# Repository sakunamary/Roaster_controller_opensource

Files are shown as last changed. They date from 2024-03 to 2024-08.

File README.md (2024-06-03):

# 全热风咖啡烘豆机主控板，适合自己diy用。

## 性能特点
- 2路温度采集：bt和inlet
- 温度采集使用max6675 k型热电偶
- 无线连接artisan
- 0-10v连续模拟输出，可以控制工业用可控硅
- 风机使用12/24v无刷控制。
- 留有I2C接口可以接扩展传感器、oled等。
  
## 目前开源板程序功能如下：
- 1：为无线接artisan记录温度数据
- 2：手动控制风力和火力。

## 相关资源
- 硬件推荐：

        1.风扇控制:模型电调(3s-4s,40A 以上的就OK)，pwm频率为50Hz，分辨率可以选择参数10（0-1024档）或者9（512档）。
        2.可控硅: MGR 2440 (0-10V，40A输出)

- 硬件开源地址：https://oshwhub.com/sakunamary/re-feng-ji-kong-zhi-ban-kai-yuan
- 固件开源地址：
  
        1.https://github.com/sakunamary/Roaster_controller_opensource

        2.https://gitee.com/sakunamary/Roaster_controller_opensource

- 操作视频：
  
        1.https://www.bilibili.com/video/BV1eg411e7H4/（怎么链接模块的Wi-Fi）
  
        2.https://www.bilibili.com/video/BV1et4y1w7i5/ （artisan怎么链接）

        3.https://www.bilibili.com/video/BV1AV4y1L7yL/ （artisan的基本操作）

## 特别提醒
本项目是开源项目，欢迎集成新功能进来、修改bug。请注意本项目的软件和硬件使用的是非商业版权授权协议的。如果需要做商业用途，请自行做闭源软硬件设计。控制原理就是那点东西了，请不要做拿来党。

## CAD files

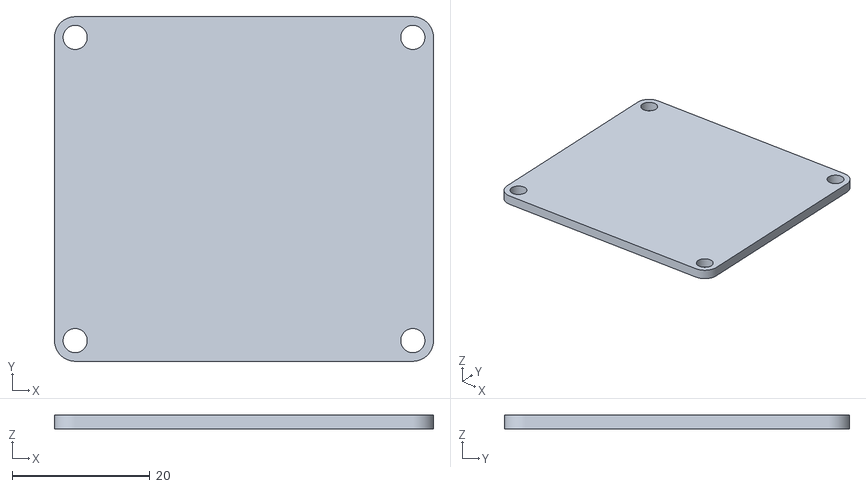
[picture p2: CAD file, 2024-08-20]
reference/保护板.stl
55.0 x 50.0 x 2.00

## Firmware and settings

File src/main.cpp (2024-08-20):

#include <Arduino.h>
#include <config.h>
#include <WiFi.h>
#include <TASK_read_temp.h>
#include <TASK_modbus_control.h>

String local_IP;

char ap_name[30];
uint8_t macAddr[6];

// HardwareSerial Serial(0);

void Task_modbus_control(void *pvParameters);
void Task_Thermo_get_data(void *pvParameters);

void setup()
{

    xThermoDataMutex = xSemaphoreCreateMutex();

    Serial.begin(BAUDRATE);

#if defined(DEBUG_MODE)
    Serial.printf("\nHOT AIR ROASTER STARTING...\n"); // 启动setup
#endif

    pwm.pause();
    pwm.write(pwm_fan_out, 0, frequency, resolution);
    pwm.write(pwm_heat_out, 0, frequency, resolution);
    pwm.resume();

#if defined(DEBUG_MODE)
    Serial.printf("\nStart PWM...\n"); // 初始化 pwm
    pwm.printDebug();
#endif

    // 初始化网络服务
    WiFi.macAddress(macAddr);
    WiFi.mode(WIFI_AP);
    sprintf(ap_name, "ROASTER_%02X%02X%02X", macAddr[3], macAddr[4], macAddr[5]);
    WiFi.softAP(ap_name, "roaster8888"); // defualt IP address :192.168.4.1 password min 8 digis

#if defined(DEBUG_MODE)
    Serial.printf("\nAP NAME:%s...\n", ap_name);
#endif

#if defined(DEBUG_MODE)
    Serial.printf("Start Task...\n");
#endif

    /*---------- Task Definition ---------------------*/
    // Setup tasks to run independently.
    xTaskCreate(
        Task_Thermo_get_data, "Thermo_get_data" // 获取温度数据的任务
        ,
        1024 * 6 // This stack size can be checked & adjusted by reading the Stack Highwater
        ,
        NULL, 1 // Priority, with 1 (configMAX_PRIORITIES - 1) being the highest, and 0 being the lowest.
        ,
        NULL // Running Core decided by FreeRTOS,let core0 run wifi and BT
    );
#if defined(DEBUG_MODE)
    Serial.printf("TASK1:Task_Thermo_get_data...\n");
#endif

    xTaskCreate(
        Task_modbus_control, "modbus_control" // 获取监控artisan操控的任务
        ,
        1024 * 10 // This stack size can be checked & adjusted by reading the Stack Highwater
        ,
        NULL, 2 // Priority, with 1 (configMAX_PRIORITIES - 1) being the highest, and 0 being the lowest.
        ,
        NULL // Running Core decided by FreeRTOS,let core0 run wifi and BT
    );
#if defined(DEBUG_MODE)
    Serial.printf("TASK2:Task_modbus_control...\n");
#endif

#if defined(DEBUG_MODE)
    Serial.printf("Start Modbus-TCP   service...\n");// 初始化Modbus-TCP服务

#endif
    mb.server(502); // Start Modbus IP //default port :502
    mb.addHreg(BT_HREG);
    mb.addHreg(ET_HREG);
    mb.addHreg(HEAT_HREG);
    mb.addHreg(FAN_HREG);

    mb.Hreg(BT_HREG, 0);   // 初始化赋值
    mb.Hreg(ET_HREG, 0);   // 初始化赋值
    mb.Hreg(HEAT_HREG, 0); // 初始化赋值
    mb.Hreg(FAN_HREG, 0);  // 初始化赋值
}

void loop()
{
    mb.task();
}

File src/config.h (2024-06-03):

#ifndef __CONFIG_H__
#define __CONFIG_H__

#include <Wire.h>

#define uS_TO_S_FACTOR 1000000 /* Conversion factor for micro seconds to seconds */
#define BAUDRATE 115200        // serial port baudrate

// #define DEBUG_MODE  //是否输出debug信息

#define VERSION "1.0.3"

#define SPI_SCK 8
#define SPI_MISO 9
#define SPI_MOSI 10

#define SPI_CS_BT 4
#define SPI_CS_ET 3

#define PWM_FAN 5
#define PWM_HEAT 2

#define I2C_SCL 7
#define I2C_SDA 6

#define TXD_HMI 21
#define RXD_HMI 20

// pwm setting
#define PWM_FREQ 50       // 最低频率不能低于50Hz，一般驱动都在1K到5K之间。
#define PWM_RESOLUTION 10 // 0-1024档 pwm分辨为2的10次方。如果需要降低就调成9，分辨率就成了2的9次方（0-512级）
// SSR控制芯片的pwm输入频率最低位50Hz
// 航模电调的pwm频率为50Hz

SemaphoreHandle_t xThermoDataMutex = NULL;

#endif

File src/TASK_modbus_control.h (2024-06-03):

#ifndef __TASK_MODBUS_CONTROL_H__
#define __TASK_MODBUS_CONTROL_H__

#include <Arduino.h>
#include <config.h>
#include <Wire.h>
#include <ModbusIP_ESP8266.h>
#include <pwmWrite.h>

bool init_status = true;

uint16_t last_FAN;
uint16_t last_PWR;

const uint32_t frequency = PWM_FREQ;

const byte resolution = PWM_RESOLUTION;
const byte pwm_fan_out = PWM_FAN;
const byte pwm_heat_out = PWM_HEAT;

Pwm pwm = Pwm();

// Modbus Registers Offsets
const uint16_t HEAT_HREG = 3003;
const uint16_t FAN_HREG = 3004;

int heat_level_to_artisan = 0;
int fan_level_to_artisan = 0;

void Task_modbus_control(void *pvParameters)
{ // function
    (void)pvParameters;
    TickType_t xLastWakeTime;
    const TickType_t xIntervel = 200 / portTICK_PERIOD_MS;
    xLastWakeTime = xTaskGetTickCount();

    for (;;)
    {
        vTaskDelayUntil(&xLastWakeTime, xIntervel);
        if (xSemaphoreTake(xThermoDataMutex, xIntervel) == pdPASS)
        {
            if (init_status)
            {
                last_FAN = mb.Hreg(FAN_HREG);
                last_PWR = mb.Hreg(HEAT_HREG);
                fan_level_to_artisan = last_FAN;
                heat_level_to_artisan = last_PWR;
            }
            else
            {
                if (last_FAN != mb.Hreg(FAN_HREG)) // 发生变动
                {
                    last_FAN = mb.Hreg(FAN_HREG);
                    fan_level_to_artisan = last_FAN;
                }
                if (last_PWR != mb.Hreg(HEAT_HREG)) // 发生变动
                {
                    last_PWR = mb.Hreg(HEAT_HREG);
                    heat_level_to_artisan = last_PWR;
                }
            }

            xSemaphoreGive(xThermoDataMutex); // end of lock mutex
        }
        // 数值转换后输出到pwm
        pwm.write(pwm_heat_out, map(heat_level_to_artisan, 0, 100, 230, 950), frequency, resolution); 
        pwm.write(pwm_fan_out, map(fan_level_to_artisan, 0, 100, 285, 350), frequency, resolution);
    }
}

#endif

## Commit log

2024-06-02 update
    修正PWM输出信号频率。
2024-06-03 update
    1.清理注释
    2.更新readme.md
